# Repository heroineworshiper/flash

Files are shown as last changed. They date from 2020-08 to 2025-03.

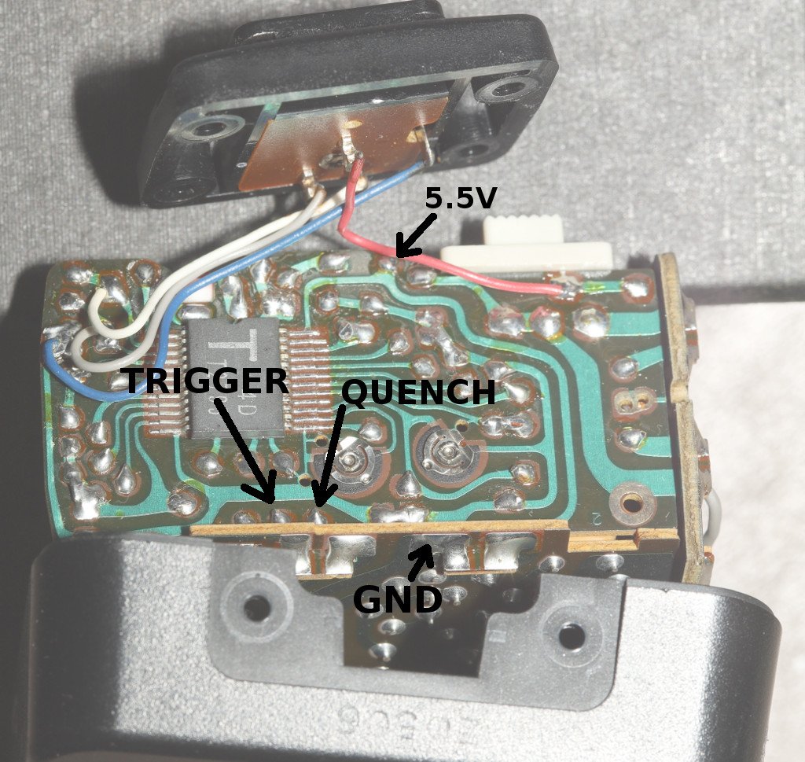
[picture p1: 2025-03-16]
flash34.jpg

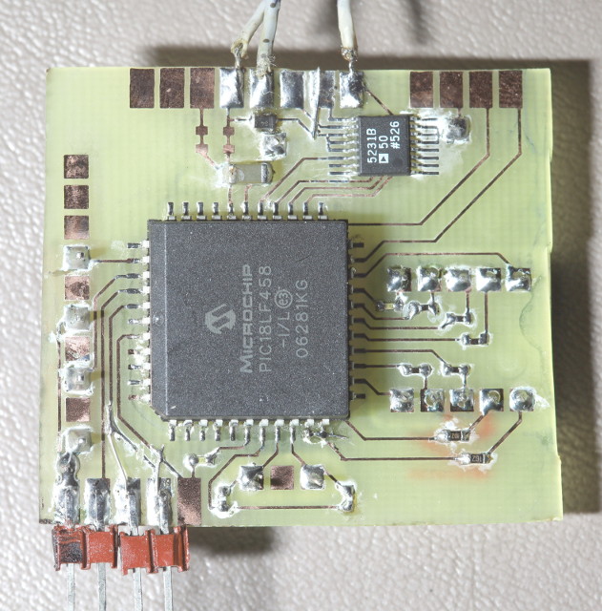
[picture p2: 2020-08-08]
resistor3.jpg

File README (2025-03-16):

What you'll find here:

----------------------------------------------------------------------------

Software to provide TTL to a Canon 244T.  This uses a double exposure
method.  The 1st exposure fires only the preflash.  The 2nd exposure
fires only the post flash with the required power.

THE 300V CAPS MUST BE COMPLETELY DISCHARGED BEFORE ANY WORK ON THE
FLASH.  The caps retain lethal voltage indefinitely after the flash is
powered off.

The 244T has a trigger signal & a quench signal inside.  The time
between the trigger & quench determines the power.  A previous design
used variable resistance to simulate a photodiode.  The latest design
only uses a timer.

The original photodiode, hot shoe must be disconnected.  Several new
connections are made to the flash.

manual_to_ttl.c: the latest program with outdated GPIOs
manual_to_ttl.pcb: the circuit board
244t.FCStd: an enclosure for the board

flash34.jpg: diagram of the flash connection points

resistor*.jpg: obsolete board in various stages of completion

flash_pot.pcb: obsolete circuit board using a junk LED readout.  Read with the
pcb program: http://pcb.geda-project.org/  It connects to the following
flash pads:

    BOARD -> FLASH
    6V -> 5.5V
    RESISTOR W -> PHOTODIODE 0V
    GND -> BATT GND
    The crystal can be any frequency down to 32khz.

usb_programmer.c: a junk PIC programmer.  The hex file is programmable
with a pickit for mortals but pickit users must create an mplab project
to write the special function registers & hex file.

flash_pot.s: the PIC firmware.  Requires gpasm to compile.

------------------------------------------------------------------------------

Convert a wired Canon ETTL flash to wireless.

A camera module emulates a flash connected to the camera.  A flash
module emulates a camera connected to the flash.  This required a 168Mhz
processor to bit bang fast enough, though the flash side might be doable
with something slower.

This requires stm32stuff to be in the parent directory.  Compile with
make wireless.bin.  Install with ../stm32stuff/uart_programmer wireless.bin

Tap the button to blink the current channel.  Hold the button to cycle
through the channels.

Enable SIM_CAM to compile the flash firmware.
Enable SIM_FLASH to compile the camera firmware.

Disable ENABLE_PRINT in the Makefile to increase robustness.

enclosure2.FCStd: Freecad models of the enclosures.
    flash top, flash bottom: flash enclosure
    camera mid, camera bottom: camera enclosure
    camera top: be sure the support layer is the shortest path

TODO: camera board should be sandwiched between the switches & hot
shoe.  This emerged as a more convenient arrangement.

wireless.c, camera.c flash.c wireless.h: STM32 firmware

bootload.c, bootloader.X: single wire bootloader for a failed PIC implementation

wireless.pcb: failed PIC board that might work on the flash side

wireless2.pcb: STM32 board that works on both sides

wireless.X: failed PIC firmware

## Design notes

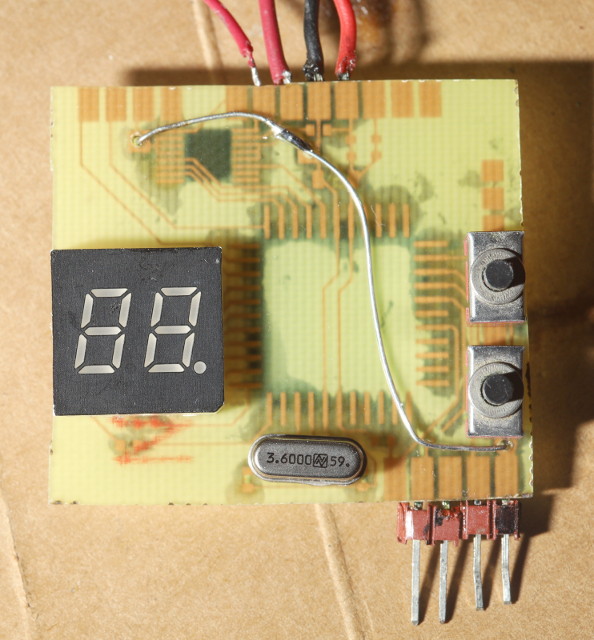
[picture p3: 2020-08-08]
resistor1.jpg

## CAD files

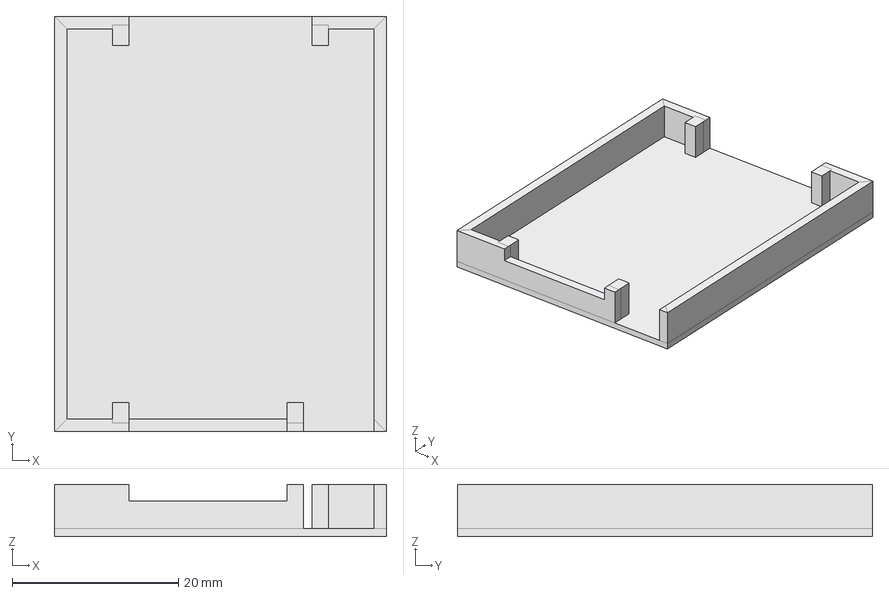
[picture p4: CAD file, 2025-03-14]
244t.FCStd
40.0 x 50.0 x 6.28 mm

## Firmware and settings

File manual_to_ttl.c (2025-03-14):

/*
 * MANUAL TO ETTL FLASH CONVERSION
 * Copyright (C) 2023-2025 Adam Williams <broadcast at earthling dot net>
 * 
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
 */

// Runs on an atmega328 to convert a manual flash to ETTL.
// Connects to the 6V, GND, trigger, & power of the flash.
// Receives commands from an ETTL to wireless transmitter wireless.bin.
// The radios can be replaced with a software FIFO to go directly from an ETTL
// hotshoe, but the transmitter side requires a much faster microcontroller.  

// make manual_to_ttl.hex
// make flash_fuse
// make flash_isp

#define F_CPU 8000000L

#include <inttypes.h>
#include <stdint.h>
#include <avr/io.h>
#include <avr/pgmspace.h>
#include <avr/interrupt.h>
#include <avr/wdt.h>
#include <util/delay.h>
#include "si4421.h"

#define bitRead(value, bit) (((value) >> (bit)) & 0x01)
#define bitSet(value, bit) ((value) |= (1UL << (bit)))
#define bitToggle(value, bit) ((value) ^= (1UL << (bit)))
#define bitClear(value, bit) ((value) &= ~(1UL << (bit)))
#define bitWrite(value, bit, bitvalue) (bitvalue ? bitSet(value, bit) : bitClear(value, bit))

#define CLAMP(x, y, z) ((x) = ((x) < (y) ? (y) : ((x) > (z) ? (z) : (x))))
#define MAX(x, y) ((x) > (y) ? (x) : (y))
#define MIN(x, y) ((x) < (y) ? (x) : (y))
#define ABS(x) ((x) < 0 ? (-(x)) : (x))

#define HZ 125
#define BAUD 200000L
#define UART_SIZE 64
uint8_t uart_buffer[UART_SIZE];
uint8_t uart_used = 0;
uint8_t uart_write_ptr = 0;
uint8_t uart_read_ptr = 0;

volatile uint8_t have_uart_in = 0;
volatile uint8_t uart_in = 0;

// handle radio recieve
void get_start1();
void (*handle_rx)() = get_start1;
uint8_t rx_counter = 0;
uint8_t packet_id = 0;
uint8_t packet_type;
// preflash power from radio packet
uint8_t preflash_power = 0;
// mane flash power from radio packet
uint8_t flash_power = 0;
// power used from 0-MAX_POWER
uint8_t power_used = 0xff;
uint8_t radio_packet[RADIO_PACKETSIZE * 2];

// RADIO_PACKETSIZE * 2
const uint8_t salt[] = 
{
    0xd0, 0xf1, 0x09, 0xa7, 0xcf, 0x89, 0x44, 0x40, 
    0xb1, 0x4c, 0x98, 0x41, 0xbc, 0xd7, 0xd1, 0x32,
    0x61, 0x8c, 0xcd, 0xa7
};

// metadata offset of offset computed from wireless.c: var_offsets
#define PREFLASH1_POWER (1 + 2)
#define MANE_FLASH1_SPEED (4 + 2)
#define MANE_FLASH1_POWER (3 + 2)


#define TOTAL_CHANNELS 4
#define MAX_POWER 7
// camera power per stop
#define CAM_PER_STOP 8
#define EXPOSURE_MIN -3
#define EXPOSURE_MAX 3
// user settings
uint8_t channel = 1;
// number of stops.  Experimentally determined by testing
// multiple apertures & ISOs
int8_t exposure_value = 2;
// 0-MAX_POWER
uint8_t manual_power = 0;
// 3 modes to work around slow recycling
#define NO_TTL 0 // manual mode
#define TTL_PREFLASH 1 // fire only preflash
#define TTL_MANEFLASH 2 // fire only mane flash using the previous preflash
// fire the preflash & the mane flash in time
#define TTL_FULL 3
uint8_t ttl_mode = TTL_PREFLASH;
//uint8_t ttl_mode = TTL_FULL;

#define RADIO_CS_GPIO PORTD
#define RADIO_CS_DDR DDRD
#define RADIO_CS_PIN 2
#define RADIO_SDO_GPIO PORTD
#define RADIO_SDO_DDR DDRD
#define RADIO_SDO_PIN 3
#define RADIO_CLK_GPIO PORTD
#define RADIO_CLK_DDR DDRD
#define RADIO_CLK_PIN 4

// AVCC must be connected for port C to work
#define LED_GPIO PORTC
#define LED_PIN 5
#define LED_DDR DDRC
#define LED2_GPIO PORTB
#define LED2_PIN 2
#define LED2_DDR DDRB

// SCR gate
#define X_PORT PORTC
#define X_PIN 1
#define X_DDR DDRC

// quench high voltage
#define POWER_PORT PORTC
#define POWER_PIN 2
#define POWER_DDR DDRC

#define LCD_CS_GPIO PORTB
#define LCD_CS_PIN 2
#define LCD_CS_DDR DDRB

#define LCD_MOSI_GPIO PORTB
#define LCD_MOSI_PIN 3
#define LCD_MOSI_DDR DDRB

#define LCD_CLK_GPIO PORTB
#define LCD_CLK_PIN 5
#define LCD_CLK_DDR DDRB

#define MODE_OUT PORTD
#define MODE_IN PIND
#define MODE_PIN 5
#define UP_OUT PORTD
#define UP_IN PIND
#define UP_PIN 6
#define DOWN_OUT PORTD
#define DOWN_IN PIND
#define DOWN_PIN 7
#define CHANNEL_OUT PORTB
#define CHANNEL_IN PINB
#define CHANNEL_PIN 7


#define TAP_TICKS (HZ / 20)
#define LONG_TICKS (HZ / 2)
#define REPEAT_TICKS (LONG_TICKS + HZ / 4)
#define BUTTON_MASK 0xf0
uint8_t button_state = 0;
uint16_t button_tick;

#define LED_TIMEOUT HZ
uint8_t led_tick = 0;

// uS values from lowest to highest power, 1 stop per entry
const int16_t delay_values[] = 
{
    0, 24, 32, 50, 70, 100, 170, 300
};

// Display driver for the LS013b7dh05
// based on 
// https://github.com/adafruit/Adafruit_SHARP_Memory_Display/blob/master/Adafruit_SharpMem.cpp
#define WIDTH 144
#define HEIGHT 168
#define WRITECMD   (0x01)
#define VCOM	   (0x02)
#define CLEAR	   (0x04)
uint8_t vcom = VCOM;


// created by ./ppmtolcd lcd.ppm
const uint8_t lcd_data[] = 
{
0x1e, 0x63, 0x0c, 0x33, 0x00, 0xbf, 0xdf, 0xe0, 0x0e, 0xbf, 0xdf, 0xe0, 0x07, 0x1e, 0x0c, 0x1e, 0x1e, 0x30, 
0x3f, 0x1e, 0x3f, 0x1e, 0x1e, 0x00, 0x00, 0x18, 0x06, 0x33, 0x77, 0x1e, 0x37, 0x00, 0x0c, 0xc6, 0x20, 0x09, 
0x0c, 0xc6, 0x20, 0x0c, 0x33, 0x0c, 0x33, 0x33, 0x38, 0x03, 0x33, 0x33, 0x33, 0x33, 0x18, 0x00, 0x0c, 0x0c, 
0x03, 0x7f, 0x33, 0x3f, 0x00, 0x0c, 0xc6, 0x20, 0x08, 0x0c, 0xc6, 0xa0, 0x09, 0x3b, 0x0e, 0x30, 0x30, 0x3c, 
0x1f, 0x03, 0x18, 0x33, 0x33, 0x18, 0x00, 0x06, 0x18, 0x03, 0x6b, 0x3f, 0x3f, 0x00, 0x0c, 0xc6, 0xa0, 0x0a, 
0x0c, 0xc6, 0x20, 0x0c, 0x37, 0x0c, 0x18, 0x1c, 0x33, 0x30, 0x1f, 0x0c, 0x1e, 0x3e, 0x7e, 0x7e, 0x06, 0x18, 
0x03, 0x63, 0x33, 0x3b, 0x00, 0x0c, 0xc6, 0xa0, 0x0b, 0x0c, 0xc6, 0xa0, 0x07, 0x33, 0x0c, 0x06, 0x30, 0x7f, 
0x30, 0x33, 0x0c, 0x33, 0x30, 0x18, 0x00, 0x06, 0x18, 0x33, 0x63, 0x33, 0x33, 0x00, 0x0c, 0xc6, 0xa0, 0x0a, 
0x0c, 0xc6, 0xa0, 0x00, 0x33, 0x0c, 0x03, 0x33, 0x30, 0x33, 0x33, 0x0c, 0x33, 0x33, 0x18, 0x00, 0x0c, 0x0c, 
0x1e, 0x63, 0x33, 0x33, 0x00, 0x0c, 0xc6, 0xaf, 0x0a, 0x0c, 0xc6, 0xaf, 0x00, 0x1e, 0x3f, 0x3f, 0x1e, 0x30, 
0x1e, 0x1e, 0x0c, 0x1e, 0x1e, 0x00, 0x00, 0x18, 0x06, 0x00, 0x00, 0x00, 0x00, 0x00, 0x00, 0x00, 0xe0, 0x0e, 
0x00, 0x00, 0xe0, 0x00, 0x00, 0x00, 0x00, 0x00, 0x00, 0x00, 0x00, 0x00, 0x00, 0x00, 0x00, 0x00, 0x00, 0x00
};
#define PPM_W 216
// input coords in lcd_data
#define CHAN_X 0
#define MANUAL_X 8
// TTL with preflash
#define TTLPRE_X 72
// TTL with mane flash
#define TTLMANE_X 40 
#define DIGIT_X 104
#define PLUS_X 184
#define MINUS_X 192
#define LPARENTH_X 200
#define RPARENTH_X 208
// output coords on LCD
// character sizes
#define QUAD_W 32
#define QUAD_H 32
#define OCTO_W 64
#define OCTO_H 64
#define MODE_CHARS 4
#define BUTTON_X (WIDTH - QUAD_W + 4)
#define C_Y 0
#define M_Y QUAD_H
#define PLUS_Y (HEIGHT - QUAD_H * 2)
#define MINUS_Y (HEIGHT - QUAD_H)
#define CURRENT_CHAN_X (QUAD_W / 2)
#define CURRENT_MODE_X 1
#define USED_X (QUAD_W / 2)
#define USED_Y (QUAD_H * 2)
#define DIGIT1_X 0
#define DIGIT1_Y (HEIGHT - OCTO_H)
#define DIGIT2_X OCTO_W
#define DIGIT2_Y (HEIGHT - OCTO_H)


// send data to the UART buffer
void send_uart(uint8_t *text, uint8_t size)
{
	uint8_t i;
	for(i = 0; uart_used < UART_SIZE && i < size; i++)
	{
		uart_buffer[uart_write_ptr++] = text[i];
		uart_used++;
		if(uart_write_ptr >= UART_SIZE) uart_write_ptr = 0;
	}
}


// send data to the debug buffer
void print_text(char *text)
{
    char *ptr = text;
    while(*ptr != 0) ptr++;
	send_uart(text, ptr - text);
}

void print_hex2(uint8_t x)
{
    char string[4];
    const char table[] = { '0', '1', '2', '3', '4', '5', '6', '7', '8', '9',
        'a', 'b', 'c', 'd', 'e', 'f' };
    string[0] = table[(x >> 4) & 0xf];
    string[1] = table[x & 0xf];
    string[2] = ' ';
    string[3] = 0;
    send_uart(string, 3);
}

void print_number(int number)
{
	char string[8];
	char *ptr = string;
	if(number < 0)
	{
		*ptr++ = '-';
		number = -number;
	}

	if(number >= 10000) *ptr++ = '0' + (number / 10000);
	if(number >= 1000) *ptr++ = '0' + ((number / 1000) % 10);
	if(number >= 100) *ptr++ = '0' + ((number / 100) % 10);
	if(number >= 10) *ptr++ = '0' + ((number / 10) % 10);
	*ptr++ = '0' + (number % 10);
	*ptr++ = ' ';
	*ptr = 0;
	print_text(string);
}

void init_serial()
{
	uint16_t baud_setting = (F_CPU / 4 / BAUD - 1) / 2;
	UBRR0H = baud_setting >> 8;
	UBRR0L = baud_setting & 0xff;
	UCSR0A = (1 << U2X0);
	UCSR0C = (1 << UCSZ01) |
		(1 << UCSZ00);
	UCSR0B = (1 << RXCIE0) |
		(1 << RXEN0) |
		(1 << TXEN0);


    uart_read_ptr = 0;
}

// write radio SPI
void write_radio_spi(uint16_t data)
{
// print_text("write_spi ");
// print_hex(data);
// print_lf();
    bitClear(RADIO_CS_GPIO, RADIO_CS_PIN);

    int i;
    for(i = 0; i < 16; i++)
    {
        if(data & 0x8000)
        {
            bitSet(RADIO_SDO_GPIO, RADIO_SDO_PIN);
        }
        else
        {
            bitClear(RADIO_SDO_GPIO, RADIO_SDO_PIN);
        }
        data <<= 1;
// need the delay if the system clock is over 16Mhz
//        usleep(1);
        bitSet(RADIO_CLK_GPIO, RADIO_CLK_PIN);
//        usleep(1);
        bitClear(RADIO_CLK_GPIO, RADIO_CLK_PIN);
    }
    
    bitSet(RADIO_CS_GPIO, RADIO_CS_PIN);
}

void set_channel()
{
    uint32_t channel2 = (uint32_t)channel * (MAX_CHANNEL - MIN_CHANNEL) / 4 + MIN_CHANNEL;
    write_radio_spi(CFSREG(channel2));
}

void init_radio()
{
// enable outputs
    bitSet(RADIO_CS_DDR, RADIO_CS_PIN);
    bitSet(RADIO_CLK_DDR, RADIO_CLK_PIN);
    bitSet(RADIO_SDO_DDR, RADIO_SDO_PIN);
    

// scan for synchronous code
    write_radio_spi(FIFORSTREG);
// enable synchron latch
    write_radio_spi(FIFORSTREG | 0x0002);
    write_radio_spi(GENCREG);
    write_radio_spi(AFCCREG);
    set_channel();
    write_radio_spi(DRVSREG);
    write_radio_spi(PMCREG);
    write_radio_spi(RXCREG);
    write_radio_spi(TXCREG);
    write_radio_spi(BBFCREG);
// receiver on
    write_radio_spi(PMCREG | 0x0080);
}

#define WRITE_SPI(x) \
{ \
/* write.  page 169 */ \
    SPDR = (x); \
/* wait.  page 168 */ \
    while(!bitRead(SPSR, SPIF)) {} \
}

#define WAIT_SPI while(!bitRead(SPSR, SPIF)) {}

// receive interrupt
ISR(USART_RX_vect)
{
	uart_in = UDR0;
	have_uart_in = 1;
}



// void load_settings()
// {
// // EEPROM address
//     EEARH = 0;
//     EEARL = 0;
// // read command
//     bitSet(EECR, EERE);
//     channel = EEDR;
// 
//     EEARL = 1;
//     bitSet(EECR, EERE);
//     exposure_value = EEDR;
// 
//     EEARL = 2;
//     bitSet(EECR, EERE);
//     manual_power = EEDR;
// 
//     EEARL = 3;
//     bitSet(EECR, EERE);
//     ttl_mode = EEDR;
//     switch(ttl_mode) 
//     {
//         case NO_TTL:
//         case TTL_PREFLASH:
//             break;
//     
//         case TTL_MANEFLASH:
//             ttl_mode = TTL_PREFLASH;
//             break;
//     
//         default:
//             ttl_mode = TTL_PREFLASH;
//     }
//     
//     CLAMP(channel, 0, TOTAL_CHANNELS - 1);
//     CLAMP(exposure_value, EXPOSURE_MIN, EXPOSURE_MAX);
//     CLAMP(manual_power, 0, MAX_POWER);
// }
// 
// void write_eeprom()
// {
// // master write enable
//     bitSet(EECR, EEMPE);
// // write enable
//     bitSet(EECR, EEPE);
// // wait for it
//     while(bitRead(EECR, EEPE))
//     {
//     }
// }
// 
// void save_settings()
// {
// // EEPROM address
//     EEARH = 0;
//     EEARL = 0;
// // data
//     EEDR = channel;
//     write_eeprom();
// 
//     EEARL = 1;
// // data
//     EEDR = exposure_value;
//     write_eeprom();
// 
//     EEARL = 2;
// // data
//     EEDR = manual_power;
//     write_eeprom();
// 
//     EEARL = 3;
// // data
//     EEDR = ttl_mode;
//     write_eeprom();
// }
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
void main()
{
// disable watchdog
	WDTCSR = 0;

// radio indicator
    bitSet(LED_DDR, LED_PIN);
    bitSet(LED_GPIO, LED_PIN);

// mane flash indicator when not using LCD
    bitSet(LED2_DDR, LED2_PIN);
    bitClear(LED2_GPIO, LED2_PIN);

// rely on data direction to get a 3.9V off voltage
//    bitClear(X_PORT, X_PIN);
//    bitClear(X_DDR, X_PIN);
    bitClear(X_PORT, X_PIN);
    bitSet(X_DDR, X_PIN);

    bitClear(POWER_PORT, POWER_PIN);
    bitSet(POWER_DDR, POWER_PIN);

    bitSet(MODE_OUT, MODE_PIN);
    bitSet(UP_OUT, UP_PIN);
    bitSet(DOWN_OUT, DOWN_PIN);
    bitSet(CHANNEL_OUT, CHANNEL_PIN);


// init the LCD
//     bitClear(LCD_CS_GPIO, LCD_CS_PIN);
//     bitSet(LCD_CS_DDR, LCD_CS_PIN);
//     bitClear(LCD_CLK_GPIO, LCD_CLK_PIN);
//     bitSet(LCD_CLK_DDR, LCD_CLK_PIN);
//     bitClear(LCD_MOSI_GPIO, LCD_MOSI_PIN);
//     bitSet(LCD_MOSI_DDR, LCD_MOSI_PIN);
// 

// tick clock prescaler page 108
// CLKio is 32khz
    TCCR0B = 0b00000100;

    uint8_t delay = HZ / 2;
    while(delay > 0)
    {
// handle tick
        if(bitRead(TIFR0, TOV0))
        {
            bitSet(TIFR0, TOV0);
            delay--;
        }
    }



	init_serial();
    print_text("\n\nWelcome to manual to ETTL\n");

//    load_settings();

    init_radio();

    uint16_t i = 0;

//    draw_screen();

// enable interrupts
	sei();

	while(1)
	{
// handle tick
        if(bitRead(TIFR0, TOV0))
        {
            bitSet(TIFR0, TOV0);
            led_tick++;
            if(led_tick >= LED_TIMEOUT)
            {
                led_tick = 0;
                bitSet(LED_GPIO, LED_PIN);
            }
            
            if((button_state & BUTTON_MASK) != BUTTON_MASK)
            {
                button_tick++;
                if(button_tick == TAP_TICKS ||
                    button_tick == LONG_TICKS ||
                    button_tick == REPEAT_TICKS)
                {
                    if(button_tick == REPEAT_TICKS)
                        button_tick = LONG_TICKS;
                    if(!bitRead(CHANNEL_IN, CHANNEL_PIN))
                    {
                        channel++;
                        if(channel >= TOTAL_CHANNELS)
                            channel = 0;
                        set_channel();
//                        save_settings();
//                        draw_screen();
                    }
                    else
                    if(!bitRead(MODE_IN, MODE_PIN) &&
                        button_tick != LONG_TICKS &&
                        button_tick != REPEAT_TICKS)
                    {
                        switch(ttl_mode)
                        {
                            case NO_TTL:
                                ttl_mode = TTL_PREFLASH;
                                break;
                            case TTL_PREFLASH:
                                ttl_mode = TTL_FULL;
                                break;
                            case TTL_MANEFLASH:
                                ttl_mode = TTL_FULL;
                                break;
                            case TTL_FULL:
                                ttl_mode = NO_TTL;
                                break;
                        }
//                        save_settings();
//                        draw_screen();
                    }
                    else
                    if(!bitRead(UP_IN, UP_PIN))
                    {
                        if(ttl_mode)
                        {
                            exposure_value++;
                            if(exposure_value > EXPOSURE_MAX)
                                exposure_value = EXPOSURE_MAX;
                        }
                        else
                        {
                            manual_power++;
                            if(manual_power > MAX_POWER)
                                manual_power = 0;
                        }
//                        save_settings();
//                        draw_screen();
                    }
                    else
                    if(!bitRead(DOWN_IN, DOWN_PIN))
                    {
                        if(ttl_mode)
                        {
                            exposure_value--;
                            if(exposure_value < EXPOSURE_MIN)
                                exposure_value = EXPOSURE_MIN;
                        }
                        else
                        {
                            manual_power--;
                            if(manual_power > MAX_POWER)
                                manual_power = MAX_POWER;
                        }
//                        save_settings();
//                        draw_screen();
                    }
                }
            }
        }

	    if(uart_used) 
	    {
	        if(bitRead(UCSR0A, UDRE0)) 
	        {
			    bitSet(UCSR0A, UDRE0); 
			    UDR0 = uart_buffer[uart_read_ptr++]; 
			    if(uart_read_ptr >= UART_SIZE) uart_read_ptr = 0; 
			    uart_used--; 
	        }
	    }

        if(have_uart_in)
        {
            have_uart_in = 0;
            handle_rx();
//            print_hex2(uart_in);
        }

        uint8_t prev_button_state = button_state;
        button_state = ((PIND & 0b11100000) >> 1) | (PINB & 0b10000000);
        if(prev_button_state != button_state)
        {
            button_tick = 0;
//print_text("BUTTON PRESS ");
//print_hex2(button_state);
//print_text("\n");
        }

    }
}

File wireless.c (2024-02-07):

/*
 * WIRELESS ETTL FLASH CONVERSION
 * Copyright (C) 2022 Adam Williams <broadcast at earthling dot net>
 * 
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
 */

// make wireless.bin
// ../stm32stuff/uart_programmer wireless.bin


#include "wireless.h"
#include "linux.h"
#include "uart.h"
#include "misc.h"
#include "stm32f4xx.h"
#include "stm32f4xx_adc.h"
#include "stm32f4xx_dac.h"
#include "stm32f4xx_rcc.h"
#include "stm32f4xx_gpio.h"
#include "stm32f4xx_iwdg.h"
#include "stm32f4xx_tim.h"
#include "stm32f4xx_flash.h"
#include "stm32f4xx_exti.h"
#include "stm32f4xx_syscfg.h"


// parsed data
// captured byte from flash
uint8_t d1_value = 0;
// captured byte to flash
uint8_t d2_value = 0;
// generated byte for D1
uint8_t d1_sim = 0xff;
// generated byte for D2
uint8_t d2_sim = 0;
int have_d2_sim = 0;
int x_value = 0;
int id_value = 0;
int bit_counter = 0;
// analog readouts
int clk_raw = 0;
int d1_raw = 0;
int d2_raw = 0;
int id_raw = 0;
// ADC is reading ID instead of D1
int reading_id = 0;
int byte_counter = 0;




// unencoded packet
uint8_t radio_packet[RADIO_PACKETSIZE * 2];


// buffer for receive/transmit
// must buffer more than 1 packet with resends
#define RADIO_BUFSIZE 128
uint8_t radio_buffer[RADIO_BUFSIZE];
volatile int radio_size = 0;
volatile int radio_write_ptr = 0;
volatile int radio_read_ptr = 0;
uint8_t radio_data;
volatile uint8_t channel = 0;
#define TOTAL_CHANNELS 4
#define CONFIG_START 0x0800c000

// RADIO_PACKETSIZE * 2
const uint8_t salt[] = 
{
    0xd0, 0xf1, 0x09, 0xa7, 0xcf, 0x89, 0x44, 0x40, 
    0xb1, 0x4c, 0x98, 0x41, 0xbc, 0xd7, 0xd1, 0x32,
    0x61, 0x8c, 0xcd, 0xa7
};
// null for debugging
// const uint8_t salt[] = 
// {
//     0x00, 0x00, 0x00, 0x00, 0x00, 0x00, 0x00, 0x00, 
//     0x00, 0x00, 0x00, 0x00, 0x00, 0x00, 0x00, 0x00, 
//     0x00, 0x00, 0x00, 0x00
// };


// send codes for flash triggers
int trigger_state = TRIGGER_IDLE;
uint8_t trigger_code = TRIGGER_CODE_NONE;




// micro seconds
// maximum time to wait for the next bit
#define BIT_TIMEOUT 40
// when to print the byte counter for debugging
#define BYTE_TIMEOUT 20000
// when to reset the packet parser because of a glitch
#define PACKET_TIMEOUT 80000
// Wait this long for trigger codes
#define TRIGGER_TIMEOUT 1000000

#define PACKET_MAX 128
// the last captured packet
// captured or simulated data to the flash
uint8_t toflash_data[PACKET_MAX];
// captured or simulated data from the flash
uint8_t fromflash_data[PACKET_MAX];
// bytes captured
int capture_size = 0;
// offset in simulated packet
int sim_offset = 0;
// size of simulated packet
int sim_size = 0;





// reference packets are for the following settings:
// 28mm 1/100 F8.0 ISO100
// ETTL, High speed, single flash, no exposure compensation

// from flash/to flash are interleaved bytes

// power on, metering start
const uint8_t poweron_ref[] = 
{
    0xff, 0xff, 0x8e, 0xb5, 0xde, 0x4c, 0x8e, 0xff, 0x8e, 0xb5, 0xde, 0x4c, 0x8e, 0xe5, 0x0d, 0xff,
    0x8e, 0xa9, 0x91, 0x25, 0x8e, 0xa1, 0x2b, 0xf8, 0x2b, 0xa5, 0x00, 0x2c, 0x8e, 0xb9, 0x00, 0x80,
    0x8e, 0xbd, 0xaa, 0x00, 0x59, 0x1c, 0x00, 0x99, 0xff, 0xfb, 0x02, 0xff, 0x8e, 0xf9, 0x55, 0xff,
    0x8e, 0xf7, 0x7b, 0xff, 0x8e, 0xb3, 0x00, 0x12, 0x00, 0x46, 0x00, 0x2f, 0x00, 0xf5, 0x57, 0xff,
    0x49, 0xff, 0x5c, 0xff, 0x0f, 0xff, 0x00, 0xbe, 0x8e, 0x14, 0x8e, 0xbb, 0x00, 0x48, 0x00, 0xff,
    0x8e, 0xe6, 0x3f, 0xff, 0x10, 0xff, 0x00, 0xff, 0x8e, 0xb7, 0x8e, 0x38, 0x8e, 0xb8, 0x8e, 0x6d,
    0x8e, 0xb4, 0x8e, 0x1d, 0x8e, 0xa8, 0x91, 0x00
};

// metering repeat
const uint8_t metering1[] =
{
    0x8e, 0xff, 0x8e, 0xb5, 0xde, 0x4c, 0x8e, 0xe5, 0x0d, 0xff, 0x8e, 0xa9, 0x91, 0x25, 0x8e, 0xa1,
    0x2b, 0xf8, 0x2b, 0xa5, 0x00, 0x2c, 0x8e, 0xb9, 0x00, 0x80, 0x8e, 0xbd, 0x18, 0x00, 0x69, 0x1c,
    0x1c, 0x99, 0xff, 0xfb, 0x02, 0xff, 0x8e, 0xf9, 0x55, 0xff, 0x8e, 0xf7, 0x7b, 0xff, 0x8e, 0xb3,
    0x00, 0x12, 0x00, 0x46, 0x00, 0x2f, 0x00, 0xf5, 0x57, 0xff, 0x49, 0xff, 0x5c, 0xff, 0x0f, 0xff,
    0x00, 0xbe, 0x8e, 0x14, 0x8e, 0xbb, 0x00, 0x48, 0x00, 0xff, 0x8e, 0xe6, 0x3f, 0xff, 0x10, 0xff,
    0x00, 0xff, 0x8e, 0xb7, 0x8e, 0x38, 0x8e, 0xb8, 0x8e, 0x6d, 0x8e, 0xb4, 0x8e, 0x1d, 0x8e, 0xa8,
    0x91, 0x00
};

// sometimes sent after poweron & metering repeat
const uint8_t metering2_ref[] =
{
    0x8e, 0xa5, 0x00, 0x2d, // X is then triggered
    0x8e, 0xa5, 0x01, 0x2c
};


const uint8_t preflash1_ref[] =
{
    0x8e, 0xff, 0x8e, 0xb4, 0x8e, 0x1d, 0x8e, 0xf2, 0xc0, 0xff, 0x8e, 0xff, 0x8e, 0xb4, 0x8e, 0x03,
    0x8e, 0xf2, 0xa0, 0xff, 0x8e, 0xb0, 0x8e, 0x80, 0x8e, 0xb1, 0x8e, 0x04, 0x8e, 0xb3, 0x00, 0x12,
    0x00, 0x46, 0x00, 0x2f, // 32ms delay
};

const uint8_t preflash2_ref[] =
{
    0x00, 0xb4, 0x8e, 0x23  // trigger follows
};


const uint8_t mane_flash1_ref[] =
{
    0x7f, 0xff, 0x8e, 0xb3, 0x00, 0x32, 0x00, 0x46, 0x00, 0x2f, 0x00, 0xf8, 0x36, 0xff, 0x8e, 0xbb,
    0x00, 0x48, 0x00, 0xff, 0x8e, 0xb7, 0x8e, 0x38, 0x8e, 0xb8, 0x8e, 0x6d, 0x8e, 0xb0, 0x8e, 0x88,
    0x8e, 0xb4, 0x8e, 0x1d, 0x8e, 0xf2, 0xc0, 0xff, 0x8e, 0xb3, 0x00, 0x36, 0x00, 0x46, 0x00, 0x2f,
    0x00, 0xb4, 0x8e, 0x3d, // trigger follows

};

const uint8_t manual_flash_ref[] =
{
    0x8e, 0xbb, 0xfb, 0x48, 0x00, 0xff, 0x8e, 0xb7, 0x8e, 0x16, 0x8e, 0xb8, 0x8e, 0x6d, 0x8e, 0xb4, 
    0x8e, 0x1d, 0x8e, 0xb4, 0x8e, 0x3d
};

const uint8_t mane_flash2_ref[] =
{
    0x7f, 0xb4, 0x8e, 0x1d, 0x8e, 0xb3, 0x00, 0x12, 0x00, 0x46, 0x00, 0x2f, 0x00, 0xfc, 0x88, 0xff,
    0xc0, 0xff, 0x1a, 0xff, 0x2a, 0xff, 0x85, 0xff, 0x78, 0xff 
};

// Different packets when shutter speed is 1/200
const uint8_t fast_flash_ref[] =
{
    0x8e, 0xb4, 0x8e, 0x25
};


// offsets of variable bytes in each packet type, null terminated
// Must be smaller than RADIO_PACKETSIZE - 2
const uint8_t poweron_vars[] = { 18, 38, 45, 47, 0 };
const uint8_t metering1_vars[] = { 15, 35, 42, 44, 46, 0 };
const uint8_t preflash1_vars[] = { 2, 11, 0 };
const uint8_t maneflash1_vars[] = { 8, 11, 13, 15, 17, 21, 24, 25, 0 };
const uint8_t maneflash2_vars[] = { 1, 0 };

int packet_type = TYPE_NONE;

// number of times to repeat each packet
const uint8_t repeats[] = 
{ 
    0, 
    2, 
    2, 
    2, 
    4, 
    2, 
    4, 
    2, 
    4,
    0
};

// tables of variables for each packet
const uint8_t *var_offsets[] =
{
    0,
    poweron_vars,
    metering1_vars,
    0,
    preflash1_vars,
    0,
    maneflash1_vars,
    maneflash2_vars,
    0,
    0
};

const int ref_packet_size[] = 
{
    0, 
    sizeof(poweron_ref) / 2,
    sizeof(metering1) / 2,
    sizeof(metering2_ref) / 2,
    sizeof(preflash1_ref) / 2,
    sizeof(preflash2_ref) / 2,
    sizeof(mane_flash1_ref) / 2,
    sizeof(mane_flash2_ref) / 2,
    sizeof(fast_flash_ref) / 2,
    sizeof(manual_flash_ref) / 2,
};

const uint8_t* ref_packets[] = 
{
    0,
    poweron_ref,
    metering1,
    metering2_ref,
    preflash1_ref,
    preflash2_ref,
    mane_flash1_ref,
    mane_flash2_ref,
    fast_flash_ref,
    manual_flash_ref,
};
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

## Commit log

2022-12-13 Wireless ETTL
2022-12-20 Fudge factor. Enclosure.
2024-02-07 ID pin handling for GODOX. Failed vintage flash conversion to ETTL
    [camera.c, flash.c, manual_to_ttl.c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]
2025-03-14 working double exposure system
    [244t.FCStd]

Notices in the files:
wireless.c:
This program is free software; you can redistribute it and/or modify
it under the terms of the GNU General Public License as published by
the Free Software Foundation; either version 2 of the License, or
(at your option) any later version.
